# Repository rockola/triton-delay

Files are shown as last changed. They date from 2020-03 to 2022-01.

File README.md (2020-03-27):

# triton-delay

Triton Delay v2-3 March 2020 by culturejam/@function_fx

These files v2-3_2 2020-03-27 by rockola

## License

"Triton Delay" by culturejam is licensed under [CC BY-SA 4.0](https://creativecommons.org/licenses/by-sa/4.0/).

## More information

[Triton Delay - Adding the "Glide" from EchoCzar to PT2399](https://www.freestompboxes.org/viewtopic.php?f=13&t=30501) on [freestompboxes.org](https://www.freestompboxes.org/)

## Images

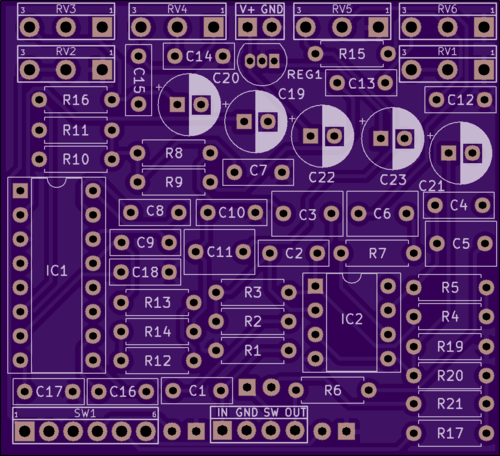
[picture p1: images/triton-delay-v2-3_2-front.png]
Front

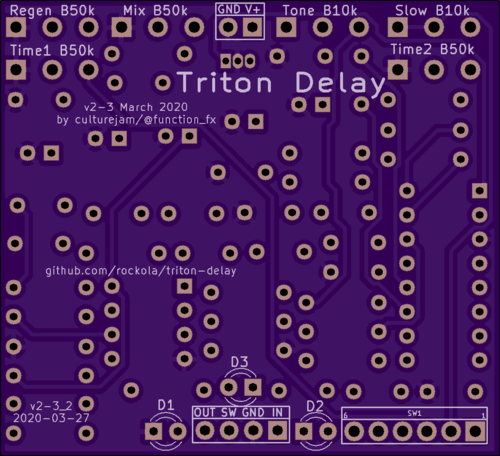
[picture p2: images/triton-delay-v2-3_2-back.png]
Back

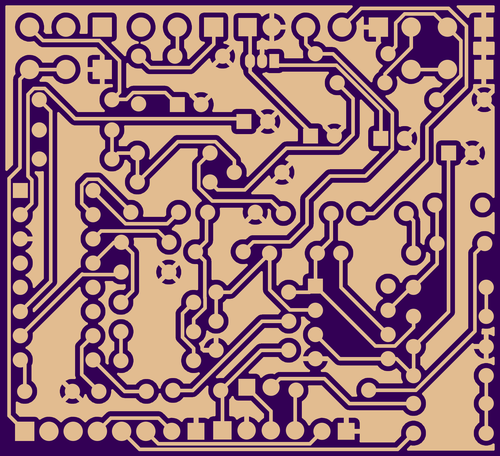
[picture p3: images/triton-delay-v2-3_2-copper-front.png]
Front copper

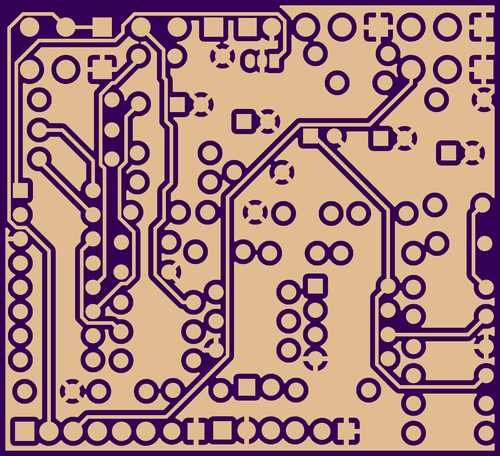
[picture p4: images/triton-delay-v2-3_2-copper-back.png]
Back copper

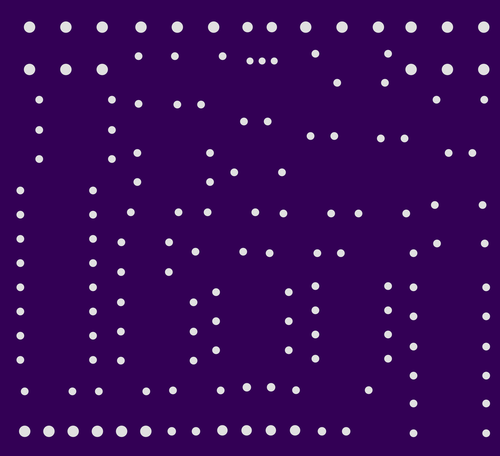
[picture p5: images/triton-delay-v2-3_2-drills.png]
Drills


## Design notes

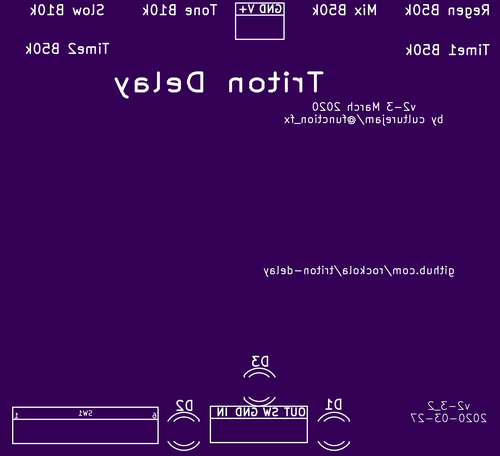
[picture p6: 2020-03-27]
images/triton-delay-v2-3_2-silkscreen-back.png

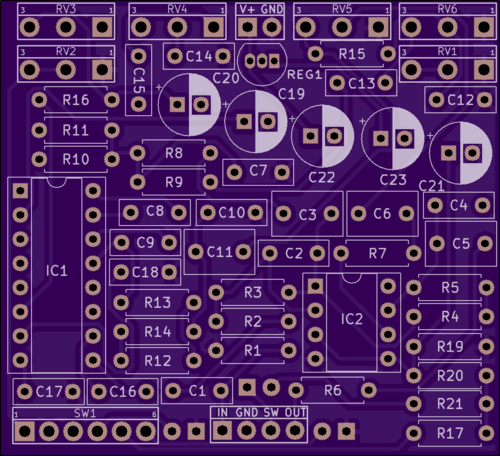
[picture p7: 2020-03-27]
images/triton-delay-v2-3_1-front.png

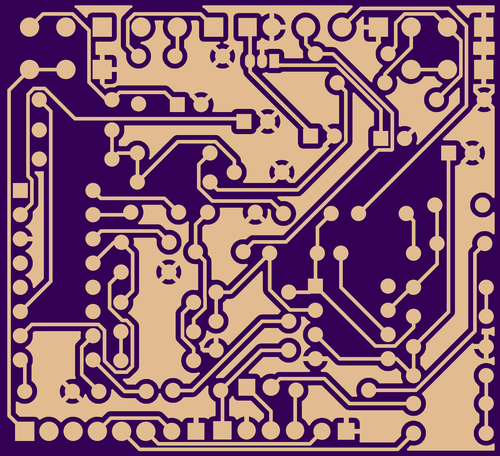
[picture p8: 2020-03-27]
images/triton-delay-v2-3_1-copper-front.png

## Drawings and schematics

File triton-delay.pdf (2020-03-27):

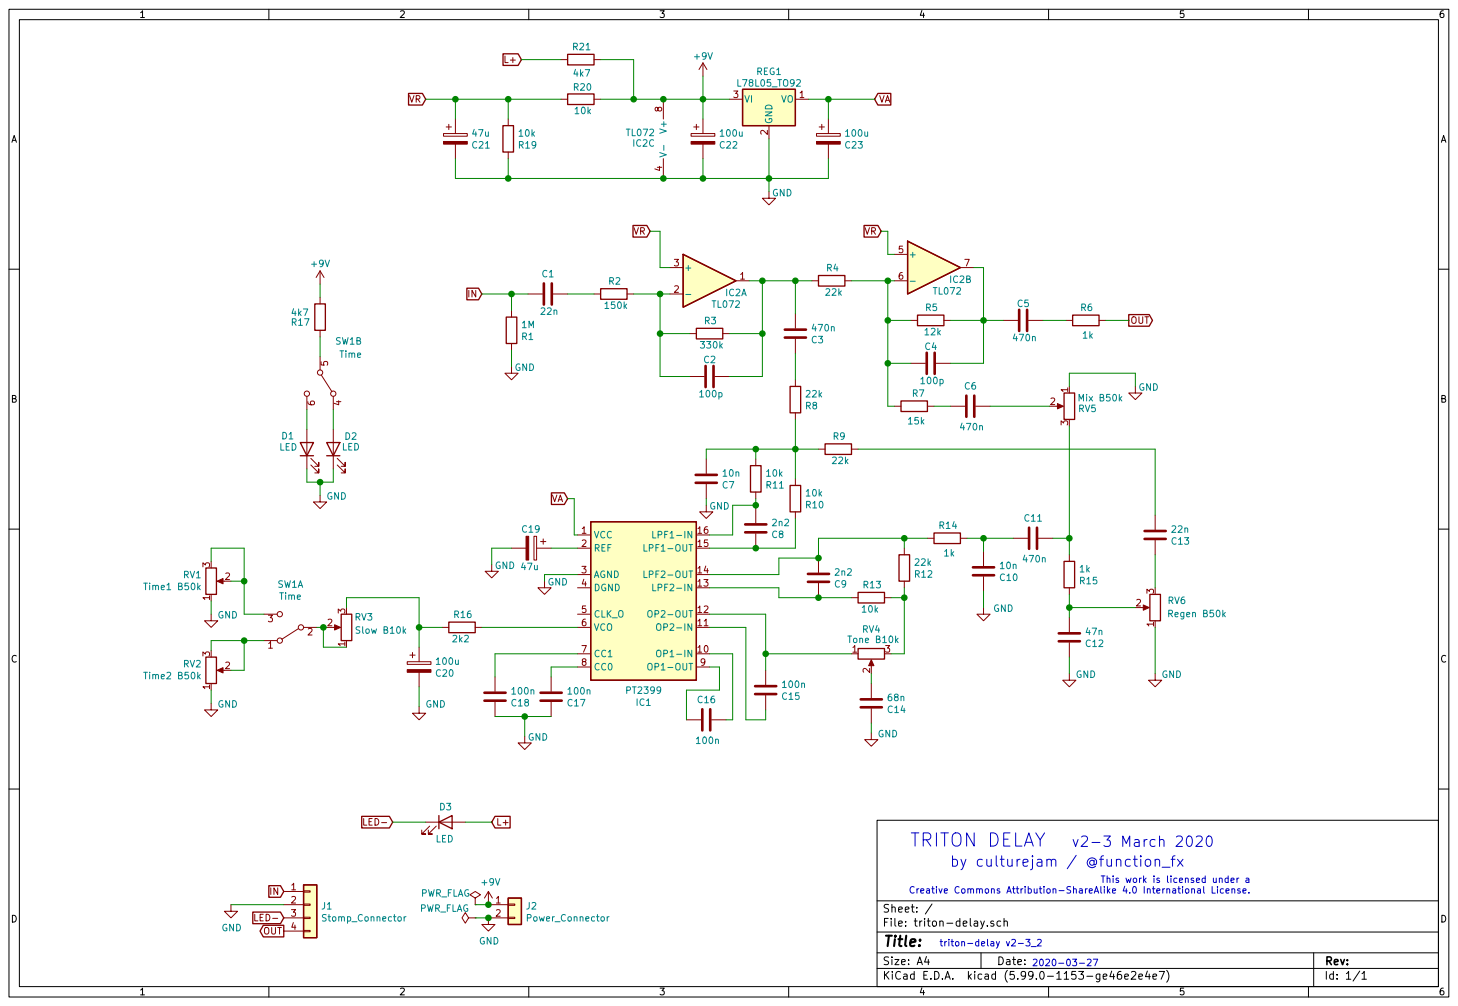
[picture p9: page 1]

File: triton-delay.sch Sheet: / C18

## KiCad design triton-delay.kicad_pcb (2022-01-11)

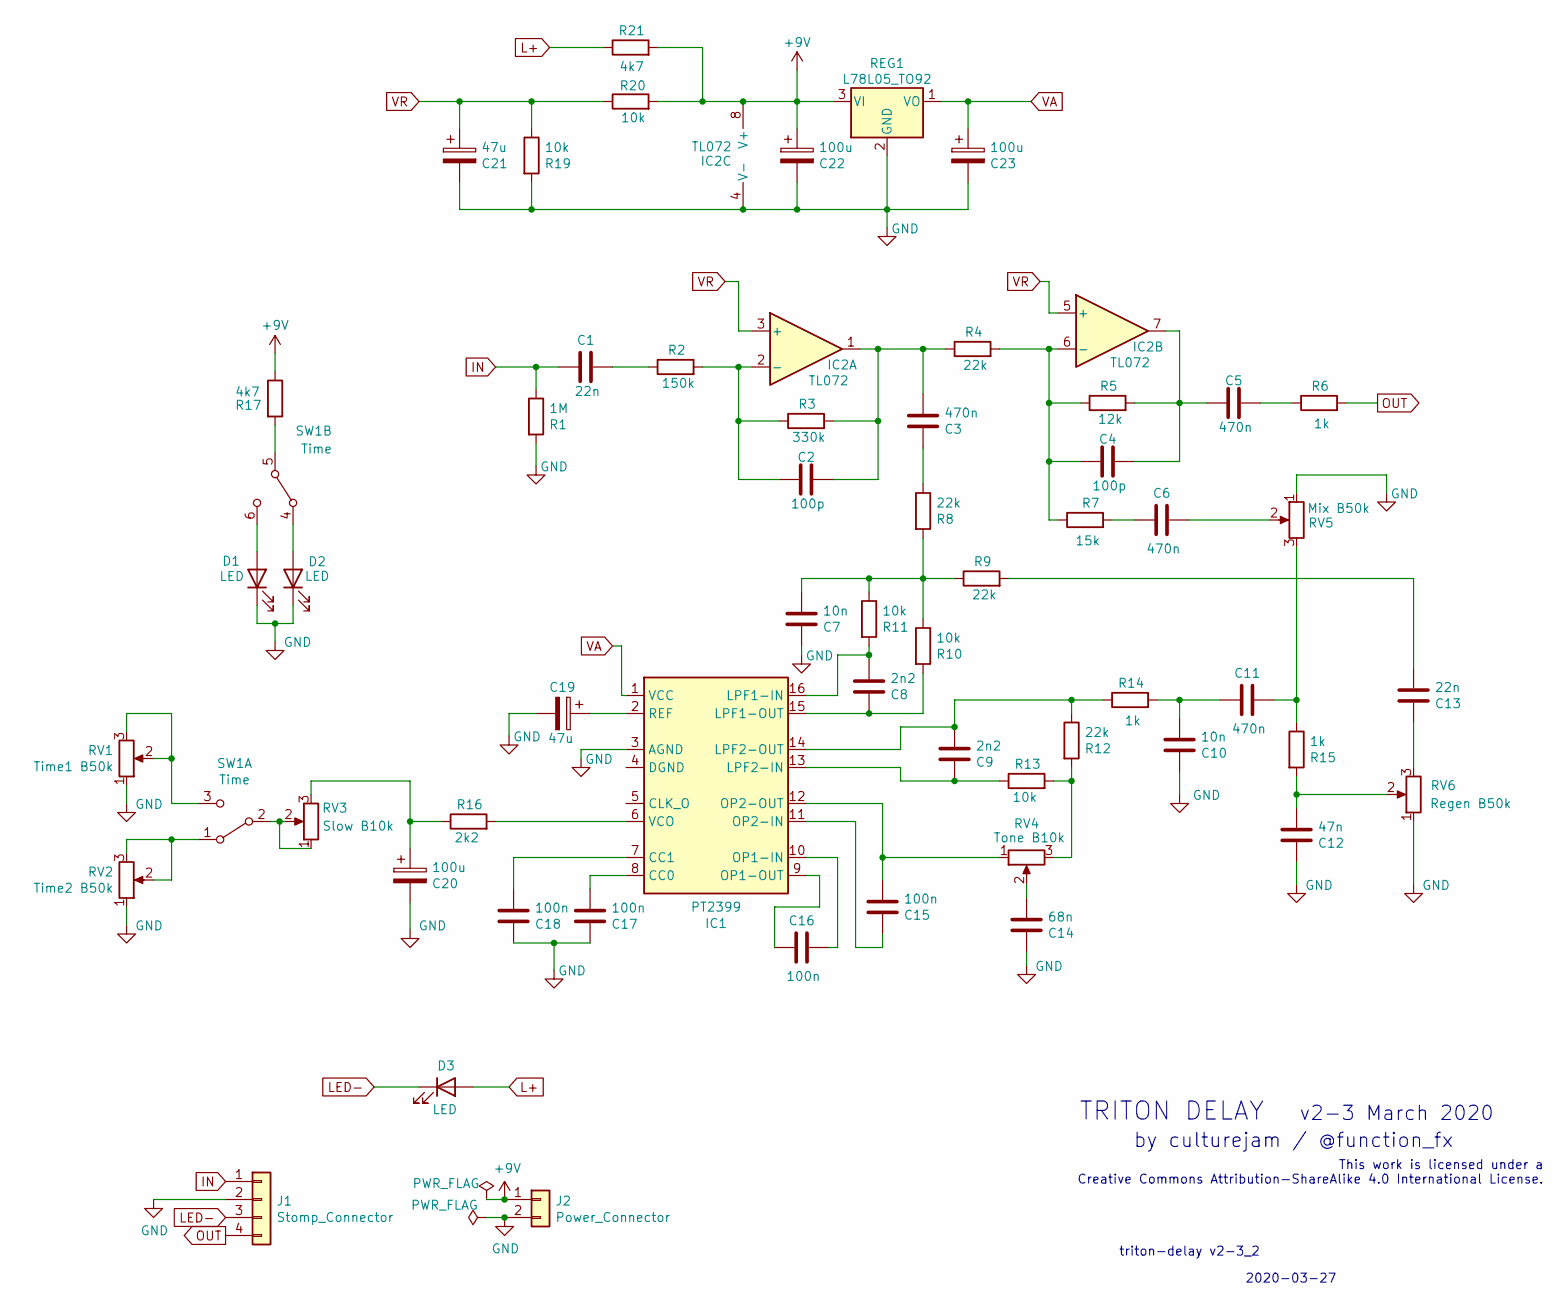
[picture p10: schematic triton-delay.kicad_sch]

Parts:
C1, C13: 22n; C_Box_7.2_2.5
C2, C4: 100p; C_Box_7.2_2.5
C3, C5, C6, C11: 470n; C_Box_7.2_4.5
C7, C10: 10n; C_Box_7.2_2.5
C8, C9: 2n2; C_Box_7.2_2.5
C12: 47n; C_Box_7.2_2.5
C14: 68n; C_Box_7.2_2.5
C15, C16, C17, C18: 100n; C_Box_7.2_2.5
C19, C21: 47u; CP_Radial_D6.3mm_P2.50mm
C20, C22, C23: 100u; CP_Radial_D6.3mm_P2.50mm
D1, D2, D3: LED; LED_D3.0mm
IC1: PT2399; DIP-16_W7.62mm_Socket
IC2: TL072; DIP-8_W7.62mm_Socket
J1: Stomp_Connector; Stomp_4pin
J2: Power_Connector; Power_Header_2pin
R1: 1M; R_DIN0207
R2: 150k; R_DIN0207
R3: 330k; R_DIN0207
R4, R8, R9, R12: 22k; R_DIN0207
R5: 12k; R_DIN0207
R6, R14, R15: 1k; R_DIN0207
R7: 15k; R_DIN0207
R10, R11, R13, R19, R20: 10k; R_DIN0207
R16: 2k2; R_DIN0207
R17, R21: 4k7; R_DIN0207
REG1: L78L05_TO92; TO-92_Inline
RV1: Time1 B50k; 16MM_PADS.2
RV2: Time2 B50k; 16MM_PADS.2
RV3: Slow B10k; 16MM_PADS.2
RV4: Tone B10k; 16MM_PADS.2
RV5: Mix B50k; 16MM_PADS.2
RV6: Regen B50k; 16MM_PADS.2
SW1: Time; DPDT.WIRE

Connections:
+9V: C22.1, IC2.8 (V+), J2.1 (PWR), R17.1, R20.2, R21.2, REG1.3 (VI)
GND: C7.2, C10.2, C12.2, C14.2, C17.2, C18.2, C19.2, C20.2, C21.2, C22.2, C23.2, D1.1 (K), D2.1 (K), IC1.3 (AGND), IC2.4 (V-), J1.2 (GND), J2.2 (GND), R1.2, R19.2, REG1.2 (GND), RV1.1, RV2.1, RV5.1, RV6.1
IN: C1.1, J1.1 (IN), R1.1
L+: D3.2 (A), R21.1
LED-: D3.1 (K), J1.3 (SW)
unnamed: C1.2, R2.1
unnamed: C2.1, IC2.2 (-), R2.2, R3.1
unnamed: C2.2, C3.1, IC2.1, R3.2, R4.1
unnamed: C3.2, R8.1
unnamed: C4.1, IC2.6 (-), R4.2, R5.1, R7.1
unnamed: C4.2, C5.1, IC2.7, R5.2
unnamed: C5.2, R6.1
unnamed: C6.1, R7.2
unnamed: C6.2, RV5.2
unnamed: C7.1, R8.2, R9.1, R10.1, R11.1
unnamed: C8.1, IC1.16 (LPF1-IN), R11.2
unnamed: C8.2, IC1.15 (LPF1-OUT), R10.2
unnamed: C9.1, IC1.14 (LPF2-OUT), R12.1, R14.1
unnamed: C9.2, IC1.13 (LPF2-IN), R13.1
unnamed: C10.1, C11.1, R14.2
unnamed: C11.2, R15.1, RV5.3
unnamed: C12.1, R15.2, RV6.2
unnamed: C13.1, R9.2
unnamed: C13.2, RV6.3
unnamed: C14.1, RV4.2
unnamed: C15.1, IC1.12 (OP2-OUT), RV4.1
unnamed: C15.2, IC1.11 (OP2-IN)
unnamed: C16.1, IC1.9 (OP1-OUT)
unnamed: C16.2, IC1.10 (OP1-IN)
unnamed: C17.1, IC1.8 (CC0)
unnamed: C18.1, IC1.7 (CC1)
unnamed: C19.1, IC1.2 (REF)
unnamed: C20.1, R16.1, RV3.3
unnamed: D1.2 (A), SW1.6 (C)
unnamed: D2.2 (A), SW1.4 (A)
unnamed: IC1.6 (VCO), R16.2
unnamed: R12.2, R13.2, RV4.3
unnamed: R17.2, SW1.5 (B)
unnamed: RV1.2, RV1.3, SW1.3 (C)
unnamed: RV2.2, RV2.3, SW1.1 (A)
unnamed: RV3.1, RV3.2, SW1.2 (B)
OUT: J1.4 (OUT), R6.2
VA: C23.1, IC1.1 (VCC), REG1.1 (VO)
VR: C21.1, IC2.3 (+), IC2.5 (+), R19.1, R20.1

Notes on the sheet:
2020-03-27
by culturejam / @function_fx
TRITON DELAY
triton-delay v2-3_2
v2-3 March 2020
This work is licensed under a Creative Commons Attribution-ShareAlike 4.0 International License.

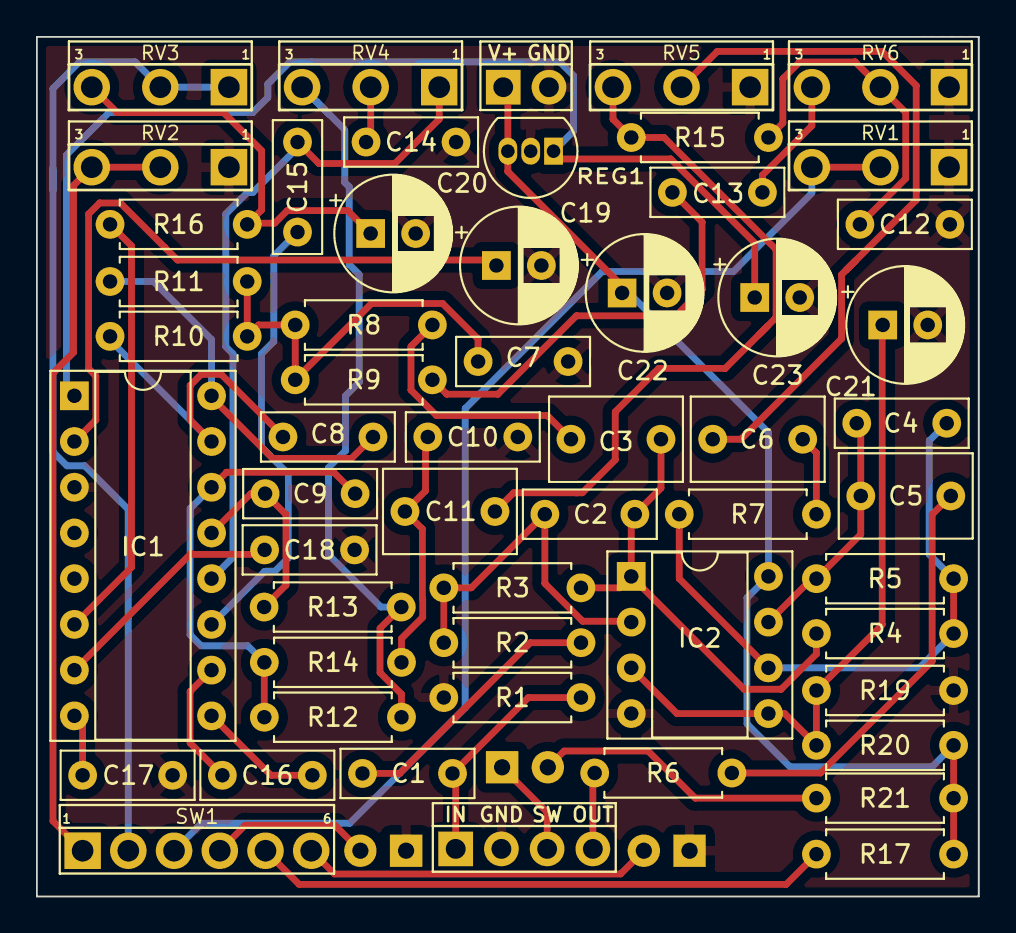
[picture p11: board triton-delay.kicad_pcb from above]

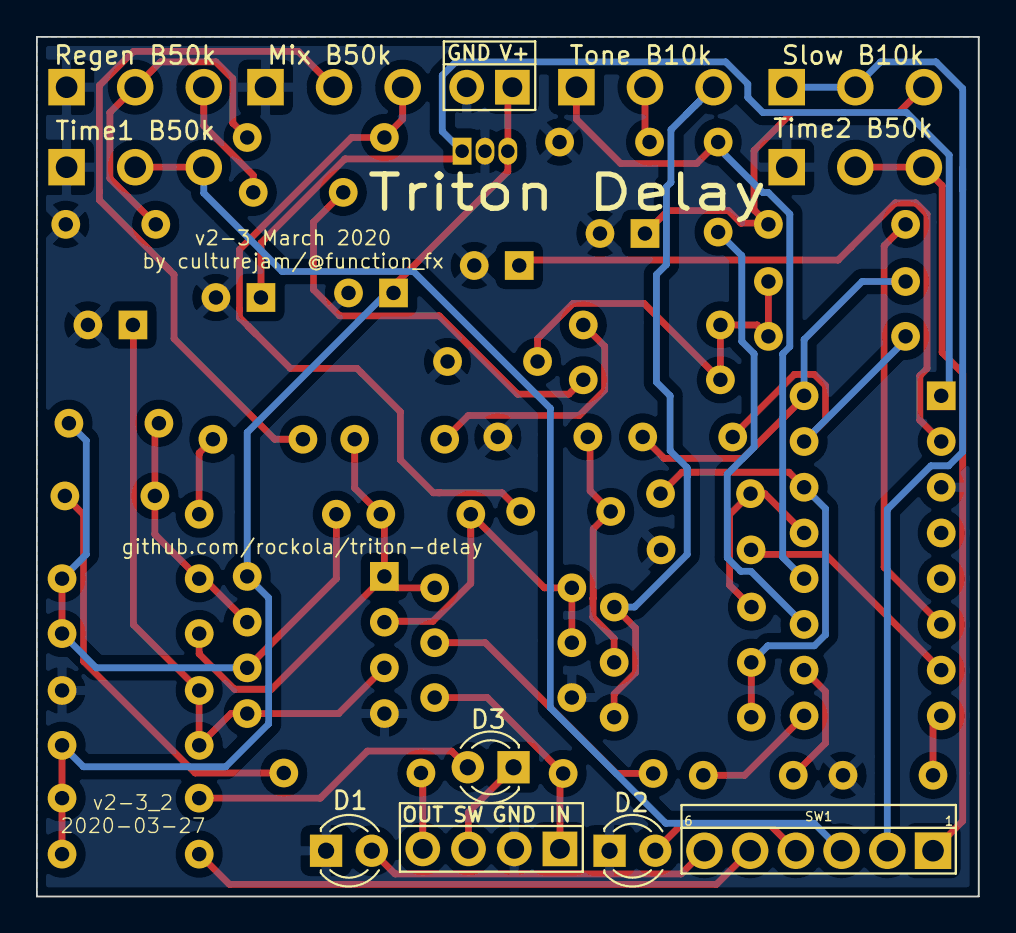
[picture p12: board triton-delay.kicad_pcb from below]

Board: 2 copper layers, 52.3 x 47.8 mm, 58 parts (3 on the bottom side), 44 nets.

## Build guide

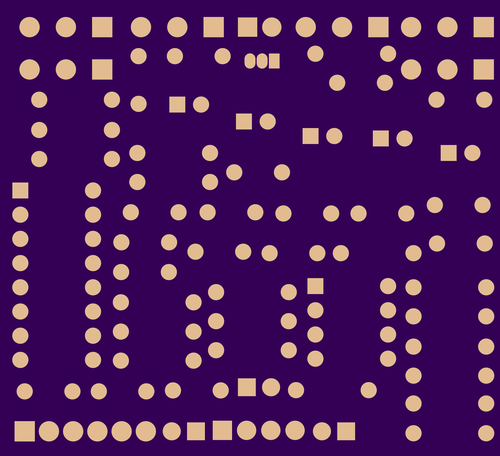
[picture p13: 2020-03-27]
images/triton-delay-v2-3_2-soldermask-front.png

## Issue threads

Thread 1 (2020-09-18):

Schematic file does not open

bennyodriscoll, 2020-09-18:
Sch file does not open in EAGLE cad

rockola, 2020-09-18:
It's a KiCAD file. Unless Eagle has KiCAD import it's not going to open. Try with the latest KiCAD nightly.

Closed 2020-09-23.

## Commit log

2020-03-27 v2-3_1: initial version
    [triton-delay-B_Cu.gbl, triton-delay-B_Mask.gbs, triton-delay-B_Paste.gbp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]
2020-03-27 pcb images
2020-03-27 v2-3_2: tied unused leg 1 of Slow B10k to wiper, moved a few traces for better ground plane coverage
    [triton-delay-B_Cu.gbl, triton-delay-B_Mask.gbs, triton-delay-B_Paste.gbp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]
2020-03-27 v2-3_2 pcb images
2022-01-11 updated to KiCad 6.0
    [triton-delay.kicad_pcb, triton-delay.kicad_sch]
